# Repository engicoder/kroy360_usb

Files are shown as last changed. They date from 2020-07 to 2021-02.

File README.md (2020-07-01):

Kroy 360 USB converter with display
======================

This converter interfaces the display and keyboard directly, bypassing the 
original main board. The controller receives key events from the keyboard 
and maps them into USB key codes which are then sent via the USB connection to 
the host. The key events are simultaneously translated into ascii characters 
to be output on the lcd display. Text from the keyboard is displayed as a single 
line which is cleared when pressing enter or escape. The key stroke count of the
current line is also displayed.

## Interfacing

The converter PCB connects to the display using the 10 pin header marked 
"DISPLAY" and to the keyboard via a 20 pin ribbon cable connected to the header
marked "KEYBOARD". The other end of the ribbon cable connects to the 20 pin 
header on the keyboard assembly. 

###  Pinouts

#### Keyboard
<table>
    <tr><td>1</td><td>P1 (pulse 1)</td><td>2</td><td>P2 (pulse 2)</td></tr>
    <tr><td>3</td><td>KS (key state)</td><td>4</td><td>EM_LED</td></tr>
    <tr><td>5</td><td>D6 (data 6)</td><td>6</td><td>TS_LED</td></tr>
    <tr><td>7</td><td>D5 (data 5)</td><td>8</td><td>CL_LED</td></tr>
    <tr><td>9</td><td>D4 (data 4)</td><td>10</td><td>GND</td></tr>
    <tr><td>11</td><td>D3 (data 3))</td><td>12</td><td>GND</td></tr>
    <tr><td>13</td><td>D2 (data 2)</td><td>14</td><td>GND</td></tr>
    <tr><td>15</td><td>D1 (data 1)</td><td>16</td><td>GND</td></tr>
    <tr><td>17</td><td>D0 (data 0)</td><td>18</td><td>GND</td></tr>
    <tr><td>19</td><td>VCC (KB pwr)</td><td>20</td><td>EX</td></tr>
</table>   

#### Display
<table>
    <tr><td>1</td><td>FLM</td></tr>
    <tr><td>2</td><td>M</td></tr>
    <tr><td>3</td><td>CL1</td></tr>
    <tr><td>4</td><td>D</td></tr>
    <tr><td>5</td><td>CL2</td></tr>
    <tr><td>6</td><td>VDD (+5V)</td></tr>
    <tr><td>7</td><td>VSS</td></tr>
    <tr><td>8</td><td>VEE (-5V)</td></tr>
    <tr><td>9</td><td>VO (bias)</td></tr>
    <tr><td>10</td><td>NC</td></tr>
</table>   

### Operation

#### Data
Data is received from the keyboard as a 7 bit scan code on data lines *D0..D6*. 
Each key position has a unique scan code. The up or down state of the key is set
by the *KS* line with a high value indicating the down state and a low value 
indicating the up state.  The *P1* line is pulled low by the keyboard when a key
state change has been detected. The converter reads the data including key state
and then pulls *P2* low momentary (~20us) to release the keyboards data latch.
If multiple keys are down, the *KS* line indicates the state of the last key change.

#### Status LEDs
The keyboard has 3 keys with integrated status LEDs; *Caps Lock*, *Type Specs* and
*Edit Mode*. Each LED has a dedicated interface line. Pulling the line low turns 
the LED on.

#### Display
The display is a Hitachi H2525 239x20 dot graphical lcd display. The display 
does not have a dedicated controller. The rows and columns of the display are 
driven by a chain of HD44104 shift registers. Data must be sent as a continuous,
synchronous data stream using data line *D* and clock line *CL2*. The *CL1* line 
latches each 239 bit row of data. The *FLM* line indicates the beginning of a new 
frame of data. Each frame is 20 rows of data. The *M* line is the polarity of the 
LCD drive voltage. The *M* line should be toggled every frame or the intensity of 
the pixels will fade. The display requires both a +5V (*VDD*) and -5V (*VEE*) 
supply. The *VO* line a bias voltage that changes the angle from which the pixels 
can be seen.

## Hardware

The custom PCB uses an ATmega32U4 microcontroller to read data from the keyboard,
drive the display, and send received key events over USB to the host by means of
a custom firmware driver. The +5V and -5V supplies for the display are generated
from the 5V provided by USB using the TC1044S charge pump. The display bias 
voltage VO is created using a potentiometer. The outer pins of the potentiometer
are attached to +5V and -5V; the center tap connected to VO. A TPS22929D load 
switch allows the firmware to control when USB 5V power is connected to the 
keyboard VCC pin. An on board LED is used for firmware status. It will flash 
during start up and once when a key event is received. 

## Firmware

The firmware is written to use the QMK keyboard firmware framework. 
https://github.com/qmk/qmk_firmware
### Build
To build the firmware:

* Clone the QMK repository and sub modules into a local folder
* Create a new folder, 'kroy360_usb', under 'qmk_firmware/keybords/converter'
* Copy the contents of the 'firmware' directory in this repository to the new 
'kroy360_usb' folder

From the qmk_firmware root:

    $ make converter/kroy360_usb:default

### Features

#### Password blanking
A custom QMK keycode, **PWD_TOG**, has been defined that can be assigned to any key.
When pressed, this keycode will toggle the password blanking feature. When active 
password blanking replaces the ascii characters for a given keystroke with an 
asterisk '*'. In the default keymap, **PWD_TOG** is assigned to the *Type Specs* 
key and the integrated LED will turn on when password blanking is active.

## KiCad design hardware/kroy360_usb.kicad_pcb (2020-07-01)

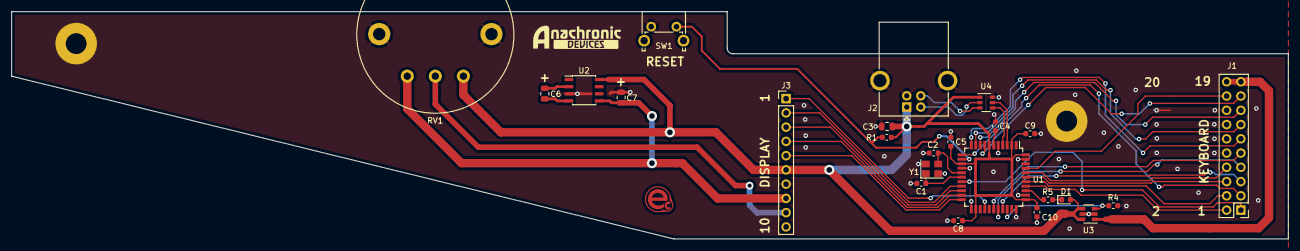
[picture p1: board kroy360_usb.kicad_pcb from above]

Board: 2 copper layers, 227.5 x 40.5 mm, 26 parts (0 on the bottom side), 37 nets.

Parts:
C1, C2: 22pF; C_0603_1608Metric
C3: 4.7uF; C_0805_2012Metric
C4: 1uF; C_0603_1608Metric
C5, C8, C9, C10: 0.1uF; C_0603_1608Metric
C6, C7: 10uF; C_0805_2012Metric
D1: LED_ALT; LED_0603_1608Metric
J1: Keyboard; PinHeader_2x10_P2.54mm_Vertical
J2: USB_B; USB_B_OST_USB-B1HSxx_Horizontal
J3: Display; PinHeader_1x10_P2.54mm_Vertical
MH1, MH2: MountingHole_Pad-Mechanical; MountingHole_3.7mm_Pad
R1, R4: 10K; R_0603_1608Metric
R5: 1K; R_0603_1608Metric
RV1: LCD Contrast; Potentiometer-Piher-T-18A
SW1: SW_Push; SW_Tactile_SPST_Angled_PTS645Vx83-2LFS
U1: ATmega32U4-AU; TQFP-44_10x10mm_P0.8mm
U2: TC1044S; SOIC-8_3.9x4.9mm_P1.27mm
U3: TPS22929D; SOT-23-6
U4: STF202; TSOP-6_1.5x3mm_P0.95mm
Y1: 16MHz/16pF; Crystal_SMD_3225-4Pin_3.2x2.5mm

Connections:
+5V: C3.1, C5.1, C8.1, C9.1, C10.1, D1.2, J2.1, J3.6, R1.1, RV1.1, U1.2, U1.7, U1.14, U1.24, U1.34, U1.44, U2.8, U3.4, U3.6, U4.1
-5V: C7.2, J3.8, RV1.3, U2.5
/CL1: J3.3, U1.20
/CL2: J3.5, U1.22
/CL_LED: J1.8, U1.40
/D: J3.4, U1.21
/D0: J1.17, U1.8
/D1: J1.15, U1.9
/D2: J1.13, U1.10
/D3: J1.11, U1.11
/D4: J1.9, U1.28
/D5: J1.7, U1.29
/D6: J1.5, U1.30
/EM_LED: J1.4, U1.38
/EX: J1.18, U1.41
/FLM: J3.1, U1.26
/KB_EN: R4.1, U1.31, U3.3
/KS: J1.3, U1.12
/LED: R5.2, U1.36
/M: J3.2, U1.19
/P1: J1.1, U1.18
/P2: J1.2, U1.37
/RESET: R1.2, SW1.2, U1.13
/TS_LED: J1.6, U1.39
/USB_DM: J2.2, U4.2
/USB_DP: J2.3, U4.3
/VKB: J1.19, J1.20, U3.1
/VO: J3.9, RV1.2
/XTAL1: C1.1, U1.17, Y1.1
/XTAL2: C2.1, U1.16, Y1.3
GND: C1.2, C2.2, C3.2, C4.2, C5.2, C7.1, C8.2, C9.2, C10.2, J1.10, J1.12, J1.14, J1.16, J2.4, J2.5, J3.7, MH1.1, MH2.1, R4.2, RV1.MP, SW1.1, U1.5, U1.15, U1.23, U1.33, U1.35, U1.43, U2.3, U3.2, U3.5, U4.6, Y1.2, Y1.4
unnamed: C4.1, U1.6
unnamed: C6.1, U2.2
unnamed: C6.2, U2.4
unnamed: D1.1, R5.1
unnamed: U1.3, U4.5
unnamed: U1.4, U4.4

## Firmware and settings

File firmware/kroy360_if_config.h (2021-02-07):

#ifndef KROY360_IF_CONFIG_H
#define KROY360_IF_CONFIG_H

#include <avr/io.h>
#include <avr/interrupt.h>

/* Pin definitions */
#define DATA_PINS   PINB
#define DATA_PORT   PORTB
#define DATA_DDR    DDRB

#define LED_PINS    PINF
#define LED_PORT    PORTF
#define LED_DDR     DDRF
#define CLLED_PIN   PF1
#define TSLED_PIN   PF4
#define EMLED_PIN   PF5
#define STLED_PIN   PF7
#define LED_BITS    ((1 << CLLED_PIN) | (1 << TSLED_PIN) | (1 << EMLED_PIN) | (1 << STLED_PIN))


#define PS2_PIN     PF6
#define PS2_PORT    PORTF
#define PS2_DDR     DDRF


#define PS1_PINS    PIND
#define PS1_PIN     PD0
#define PS1_PORT    PORTD
#define PS1_DDR     DDRD
#define PS1_INT     INT0_vect


#define KBEN_PINS    PINC
#define KBEN_PIN     PD6
#define KBEN_PORT    PORTC
#define KBEN_DDR     DDRC

typedef enum kroy360_led_e
{
    KROY360_LED_CL = (1 << CLLED_PIN),
    KROY360_LED_TS = (1 << TSLED_PIN),
    KROY360_LED_EM = (1 << EMLED_PIN),
    KROY360_LED_ST = (1 << STLED_PIN),
    KROY360_LED_ALL = LED_BITS,
} kroy360_led_e;

#endif

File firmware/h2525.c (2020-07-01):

#include <stdint.h>
#include <stdbool.h>

#include <avr/interrupt.h>
#include <util/delay.h>

#include "h2525.h"
#include "h2525_pins.h"


#define LCD_ROWS 20
#define LCD_COLS 240

volatile uint8_t gram[LCD_ROWS*LCD_COLS/8] = {0};
volatile uint8_t col_idx = 0;
volatile uint8_t row = 0;
volatile bool m_pos = false;


static void init_pins(void)
{
    PIN_CONFIG_OUT_LOW(H2525_FLM);
    PIN_CONFIG_OUT_LOW(H2525_M);
    PIN_CONFIG_OUT_LOW(H2525_CL1);
}




#define BAUD 400000
#define BAUD_VALUE ((F_CPU)/(2UL*BAUD)-1)

#define USART_XCK H2525_CL2

#ifndef UCPHA1
#define UCPHA1 1
#endif

/* USART SPIM implemenation
 * ---------------------------------------------------------------------- */
void usart_spim_init(void)
{
    // Baud rate must be set to 0 prior to enabling the USART as SPI
    // master, to ensure proper initialization of the XCK line.
    UBRR1 = 0;

    // Set XCK line to output, ie. set USART in master mode.
    DDRD |= (1 << PD5);

    // Set USART to Master SPI mode.
    UCSR1C = (1 << UMSEL11) | (1 << UMSEL10) | (0 << UCPHA1) | (1 << UCPOL1);
}

void usart_spim_int_enable(void)
{
    col_idx = 0;
    row = 0;
    m_pos = false;
    PIN_HIGH(H2525_FLM);

    UCSR1B = (1 << TXEN1) | (1 << TXCIE1) | (1 << UDRIE1);
    UBRR1 = BAUD_VALUE;
    sei();
}

ISR(USART1_TX_vect)
{

    row++;
    if (row == LCD_ROWS)
        PIN_HIGH(H2525_FLM);
    _delay_us(2);
    PIN_HIGH(H2525_CL1);
    _delay_us(1);
    col_idx = 0;
    if(row == LCD_ROWS)
    {
        m_pos = !m_pos;
        if (m_pos)
            PIN_HIGH(H2525_M);
        else
            PIN_LOW(H2525_M);
        _delay_us(1);
    }
    PIN_LOW(H2525_CL1);
    _delay_us(1);
    if(row == LCD_ROWS)
    {
        PIN_LOW(H2525_FLM);
        row = 0;
    }
    UCSR1B |= ((1 <<TXEN1) |(1 << UDRIE1));
}


ISR(USART1_UDRE_vect)
{
/*
    if (col_idx == 2)
        PIN_LOW(H2525_FLM);
    else if ((row == LCD_ROWS-1) && (col_idx == LCD_COLS/8 - 2))
        PIN_HIGH(H2525_FLM);
    else if (col_idx == LCD_COLS/8 - 1)
        PIN_HIGH(H2525_CL1);
*/
    if (col_idx < LCD_COLS/8 - 1)
    {
        /*
        uint8_t data = gram[row * col_idx];
        if (m_pos)
            UDR1 = data;
        else
            UDR1 = ~data;
        */
        UDR1 = gram[row * LCD_COLS/8 + col_idx];
        col_idx++;
    }
    else
    {
        UDR1 = gram[row * LCD_COLS/8 + col_idx];
        col_idx++;
        UCSR1B &= ~((1 <<TXEN1) |(1 << UDRIE1));
    }

}


void h2525_init(void)
{
    init_pins();
//    init_timer();
    usart_spim_init();
}

void h2525_start(void)
{
//    timer_int_enable();
    usart_spim_int_enable();
}

void h2525_clear(void)
{
    for(int i = 0; i < sizeof(gram); i++)
    {
        gram[i] = 0;
    }
}

void h2525_set_pixel(uint8_t x, uint8_t y)
{
    uint16_t pixel_index = y * LCD_COLS + x;
    uint16_t  pixel_byte = pixel_index / 8;
    uint8_t pixel_bit = pixel_index % 8;

    gram[pixel_byte] |= (1 << (7-pixel_bit));
}
void h2525_clear_pixel(uint8_t x, uint8_t y)
{
    uint16_t pixel_index = y * LCD_COLS + x;
    uint16_t  pixel_byte = pixel_index / 8;
    uint8_t pixel_bit = pixel_index % 8;

    gram[pixel_byte] &= ~(1 << (7-pixel_bit));
}

void h2525_clear_region(uint8_t start_x, uint8_t start_y, uint8_t width, uint8_t height)
{
    uint8_t end_x = start_x + width;
    uint8_t end_y = start_y + height;

    for (uint8_t y = start_y; start_y < end_y; y++)
    {
        for (uint8_t x = start_x; x < end_x; x++)
        {
            h2525_clear_pixel(x, y);
        }
    }
}


#if 0
#define TIMER_PERIOD_A 120
#define TIMER_PERIOD_B TIMER_PERIOD_A/2
static void init_timer(void)
{
    /* Enable CTC mode and stop timer by selecting no clock source*/
    TCCR1A = 0;
    TCCR1B = (1 << WGM12);

    OCR1A = TIMER_PERIOD_A;
    OCR1B = TIMER_PERIOD_B;

    /* Reset counter */
    TCNT1 = 0;
}

static void timer_int_enable(void)
{
    /* Reset counter */
    TCNT1 = 0;

    /* Clear the Compare Match flags*/
    TIFR1 = (1 << OCF1A);
    TIFR1 = (1 << OCF1B);

    /* Enable interrupt on Compare Match */
    TIMSK1 |= 1 << OCIE1A;
    TIMSK1 |= 1 << OCIE1B;

    /* Start timer by selecting CLk source  (1 presecaler)*/
    TCCR1B |= (1 << CS10);
}

#if 0
static void timer_int_disable(void)
{
    /* Stop timer by selecting no clock source but leaving CTC mode*/
    TCCR1B = (1 << WGM12);

    /* Disable Compare Match interrupts */
    TIMSK1 &= ~(1 << OCIE1A);
    TIMSK1 &= ~(1 << OCIE1B);

    /* Clear the Compare Match flags*/
    TIFR1 = (1<<OCF1A);
    TIFR1 = (1<<OCF1B);

}
#endif

#define TIMER_INTA TIMER1_COMPA_vect
#define TIMER_INTB TIMER1_COMPB_vect
volatile uint8_t byte_idx = LCD_COLS/8 - 1;
volatile uint8_t bit = (1 << 6);
volatile uint8_t row = LCD_ROWS - 1;
volatile uint8_t byte_curr = 0xAA;
/* Compare B sets CL2 low */
ISR(TIMER_INTB)
{
    if ((row == LCD_ROWS - 1) && (byte_idx == LCD_COLS/8 - 1) && bit == (1 << 6))
        PIN_HIGH(H2525_FLM);

    if ((byte_idx == LCD_COLS/8 - 1) && (bit == (1 << 7)))
    {
        PIN_HIGH(H2525_CL1);
        byte_idx = 0;
        bit = 1;
        row++;
        byte_curr = gram[byte_idx];
        if (row == LCD_ROWS)
            row = 0;
    }
    else
    {
        if (bit == (1 << 7))
        {
            bit = 1;
            byte_idx++;
            byte_curr = gram[byte_idx];
        }
        else
            bit <<= 1;
    }

    PIN_LOW(H2525_CL2);
}

/* Compare B sets CL2 high */
ISR(TIMER_INTA)
{
    if (byte_idx == 0 && bit == 1)
    {
        PIN_LOW(H2525_CL1);
        if (row == 0)
            PIN_TOGGLE(H2525_M);
    }
    else if ((row == 0) && (byte_idx == 0) && (bit == (1 << 5)))
    {
        PIN_LOW(H2525_FLM);
    }

    uint8_t pixel = byte_curr & bit;
    if (pixel == 0)
        PIN_LOW(H2525_D1);
    else
        PIN_HIGH(H2525_D1);
    PIN_HIGH(H2525_CL2);
}
#endif
